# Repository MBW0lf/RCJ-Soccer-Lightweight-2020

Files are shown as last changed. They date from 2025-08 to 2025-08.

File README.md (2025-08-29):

# ⚽ Nemesis – Junior Soccer Lightweight Robot

This project is a soccer-playing robot developed by the Nemesis team from Allame Helli 5 High School for the IranOpen RoboCup competition. The robot is designed to detect, chase, and control an infrared-emitting ball, navigate the field, and play both offensive and defensive roles.

## 🛠 How it works
- Ball detection using IR sensors (IRM8601S) placed around the robot.  
- Positioning & orientation with a GY-25 gyroscope module.
- Line detection with multiple LDR sensors to avoid going out of bounds.  
- Offensive & defensive algorithms to coordinate striker and goalkeeper roles.  

## 🔧 Hardware Components
- **STM32F103C8T6**: 32-bit ARM microcontroller for main control 
- **IRM8601S IR Sensors**: ball detection in 16 directions 
- **GY-25 Gyroscope**: orientation tracking 
- **SHARP GP2D120 Sensors**: distance measurement for walls and positioning 
- **L6203 Motor Drivers**: high-current motor control  
- **DC Gear Motors (555 RPM)**: omnidirectional movement with mecanum/omni wheels
- **LDR Sensors**: line detection for field boundaries 
- **Custom PCBs**: lightweight structure and reduced wiring

## 📡 Communication
- Sensor data is read via **ADC** and **multiplexers** (4067 ICs).
- Motor control is handled by **PWM signals** from STM32.
- Algorithms adjust speed and direction based on ball position, field boundaries, and opponent location. 

## 🤖 Roles
- Striker: Actively chases the ball and aims for the opponent’s goal.
- Goalkeeper: Maintains position near own goal, intercepts incoming shots.

## 🚀 Innovations
- Increased number of **LDR sensors** for higher boundary detection accuracy.
- Dual multiplexer system to handle large numbers of sensors with limited pins.
- Modular design allowing quick replacement of gyroscope or compass modules.
- LCD display for real-time debugging and sensor data visualization.

## Summary
The Nemesis robot demonstrates how **sensor fusion, mechanical design, and embedded programming** can be combined to create a competitive RoboCup soccer robot. Its design focuses on **speed, precision, and adaptability** in dynamic match conditions.  

---

✨ *Thanks for checking out this project!*

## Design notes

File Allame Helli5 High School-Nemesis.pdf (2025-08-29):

پانزدهمین دوره مسابقات بینالمللی ربوکاپ آزاد ايران دانشگاه آزاد اسالمی قزوين و کمیته ملی ربوکاپ ايران
تهران | فروردين 1399

## گزارش فنی تیم Nemesis

### (Junior Soccer Light Weight)

،محمد مهدی قاسمی | 1 | طاها علیخانی

2

3 ،امیرحسین کشاورز
،سیدامیرعلی نواده

4
تهران،میدان فردوسی،خیابان ایرانشهر،دبیرستان پسرانه تیزهوشان عالمه حلی5
NemesisteamH5@gmail.com

## چكیده

در این مقالهه بهه شهرر مراحها یراحهی و سهاخه رباتههال فوتتالیسهه تهی Nemesis پرداختهه شهدا اسههارباا ههال ایهن تی متشکا از سهه بشها ایهلی مکانیل،الکترونیهل،التوریت و برنامهه نویسهی اسهها مها بها اسهتاادا از هههار موتهور DC کهه سهرعتی حهدود پانصهد و پنجهاا و پهن دور در دقیقهه و ههره ههال خورشهیدل trans)کهه امکهان حرکهه در تههامی ههاا را با هدف دنتها کهردن تهو بهرال ربهاا فهراه مهی کنهد اسهتاادا کهردا ای اسهشه افهزار یراحهی شهدا توانهایی تشهشی پههالم مههادون قرمههز ارسههالی از تههو را بههه کهههل سنسههور هههال 8601IRM دارد و پههم از تشههشی تههو ، دسههتور ههها و فرمان کنترلی الزم توسه میکروکنترلهر 32STM بهه درایهور موتهور 6203L ارسها مهی شهودادر ههر کهدام از ایهن بشها هها زیر مجهوعه هایی و ود دارد که در ادامه به یور کاما به آن ها اشارا می کنی ا

IRM8601 ، L6203 ، STM32F103C8T6 ، DC | موتور | : | کلیدی | واژههای

## .1 مقدمه

ربات ها ، بازیگران عصر تكنولوژی: انجام بعضهی ازامهور بهرال مها انسهان هها شهاید بسهیار خسهته کننهدا و عهدا آور باشهدا امها بعضهی از امهور حتهها بایهد انجهام شهوندا پهم مها دو راا بیشهتر نهداری او اینکهه کهار ههال خهود را بها هههان سهشتی انجهام دههی یها اینکهه بها اسهتاادا از ذههن خهالخ خهود امهور را بهه بهازیتران عصهر تکنولهویل بسهتاری ارباا هها هههان بهازیتران عصهر تکنولهویل هستند بازیترانی که روز به روز بیشهتر خهود را در معهری دیهد عههوم میتدارنهدااز ارسها بسهته ههال پسهتی رفتهه تها حتی ورزش مههی و پریرفهدار فوتتها کهه مهورد تو هه تهی مها قهرار رفهه و بهه فکهر تشهکیا تهی ربهاا فوتتالیسهه ستل وزن و شرکه در مسابقاا ایران اپن پرداختی ا

-1 برنامه نویسی
-2 الکترونیل و مکانیل
-3 الکترونیل و مکانیل
-4 برنامه نویسی

تهران | فروردين 1399

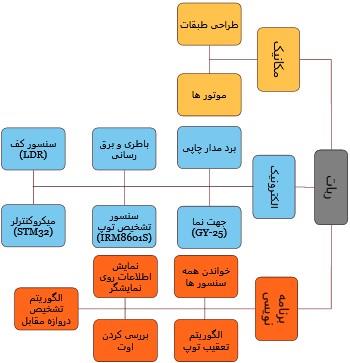
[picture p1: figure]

شكل :1یار تا ید رباا در یل نتاا

## .2 سیستم حرکتی:

.2.1 مكانیک سیستم حرکتی:

.2.1.1 بدنه
- بدنه رباا به یور کلی شاما سه یتقه میتاشد که هر یتقه از نم مدار هاپی و در برنامه DESIGNER ALTIUM یراحی شدا اسه:
- شاسی یا کای رباا از ههار موتور و هره ها و مدار LDR تشکیا شدا اسها
- بشا دوم محا قرار یرل سنسور هال مادون قرمز 8601IRM (اسهاکه کار تششی تو را انجام می دهندا
- بشا سوم محا قرار یرل باقی قطعاا الکترونیکی اسها

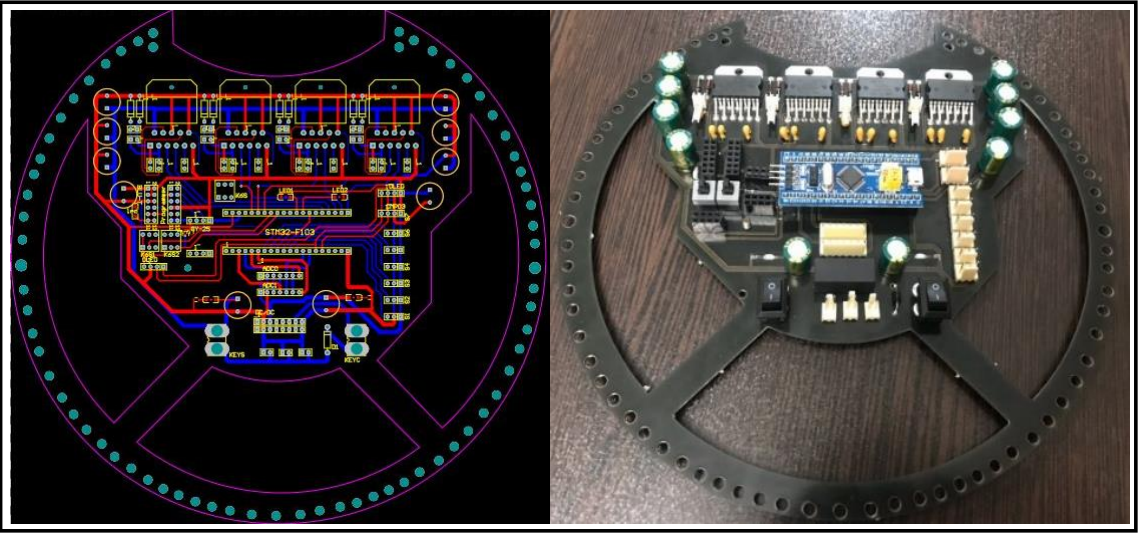
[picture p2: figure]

شكل:2 نهال رول رباا

تهران | فروردين 1399

.2.1.2
موتور ها و چرخ ها:
سیستم دو موتور و دوچرخ: با تو ه به اینکهه ههر ههه تعهداد موتهور هها کهتهر باشهد وزن نههایی ربهاا نیهز کهتهر میشهود،پم بهتهر اسهه کهه از دو موتهور قهویتر بها امکانهاا بیشهتر اسهتاادا کهرد، بهه ایهن منتهور مهی بایسههه دو موتهور بها زاویهه180 در ه نسته به هه و و 90 در هه نسهته بهه لهول ربهاا قهرار یرنهدا در نتیجهه یتها ایهن سیسهت ،رباا مهی توانهد در دو ههه ایهلی حرکهه کنهدااما در ایهن یهورا سهرعه عکهم العهها و قهدرا مهانور رباا کهتر می شودا در نتیجهه زمهان زیهادل نسهته بهه دیتهر سیسهت هها بهرال بهه دسهه آوردن تو ،باز شهه بهه دروازا و ااا تلف می شودا به این دالیا ما از این سیست استاادا نکردا ای ا سیستم سه موتور و سه چررخ: بهرال داشهتن سهرعه مناسهت ههه مهانور و عکهم العهها میتهوان از سیسهت سهه موتههور و سهه ههره اسهتاادا نههود. بهرال اسهتاادا از ایهن سیسهت مهی بایسهه موتورهها بازاویهه120در هه نسته به هه قهرار یرنهدا ایهن سیسهت بهه 6 ههه ایهلی و 6 ههه فرعهی تهوان حرکتهی داردا ایهن سیسهت بهه یور نستی از سرعه،مانور باال و ههچنین وزن ک برخوردار اسه اما سرعه مطلو مورد نیاز ما را نداردا

شكل :3 حاله هال مشتلف قرار یرل هره ها سیستم چهار موتور و چهرار چررخ: در ایهن سیسهت بهه دلیها اسهتاادا از هههار موتههور،ربههاا توانههایی مههانور و عکم العهها سهریر را داردا در ایهن سیسهت 4 موتهور بها زاویهه 45 در هه نسهته بهه هه اسهتاادا شهدا اسهه و ربهاا مهی توانهد در 8 ههه ایهلی و 8 ههه فرعهی حرکهه کنهدا در ایهن سیسهت تهراز بهودن ههر هههار ههره اههیهه بهاالیی دارد و ههچنهین بها تو هه بهه تعهداد موتهور هها و محهدودیه وزنهی مشهش شهدا از سهول کهیتهه مسههابقه بایههد از موتههور هههال سههتل تههر و اههعیف تههر اسههتاادا کنههی ا مهها از موتههور هههال تههایوانی GEAR DC MOTOR بها ولتهای کهارل-15 9 ولهه و 555 دور در دقیقهه اسهتاادا کهردا ایه کهه بیشهتر شهاخ ههال مهورد نیاز ما را دارا هستندا

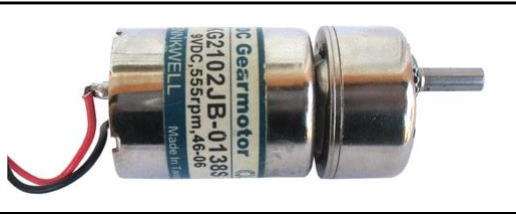
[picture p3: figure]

شكل:4 مششصاا موتور

KG2102JB-0138S | مد شهارا
یو : 45 میلی متر | ابعاد شعاع: 25 میلی متر
| بازا ولتای کارل 9-15 وله
| تعداد دور در دقیقه rpm )555 دور در دقیقه
| وزن 75 رم

تهران | فروردين 1399

چرخهای خورشیدی:
هره ههال تهرنم خورشهیدل( ههره ههایی هسهتند کهه از یهل ههره سهادا و تعهدادل ههره هرز هرد متصها بهه هره ایلی تشکیا شدا اندا ساختار ایهن ههره هها یهورل یراحهی شهدا اسهه کهه قابلیهه حرکهه در دو ههه را داراسه و این قابلیه، امکان حرکهه ربهاا در ههاا مشتلهف را آسهان تهر و سهریر تهر مهی کنهدا سهتل بهودن نیهز از ویژ ی هال مثته این هره هاسها

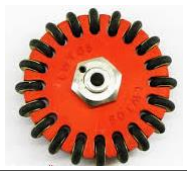
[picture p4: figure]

شكل :5 هره خورشیدل
.2.2 مدارات:
:stm32f103 | میكروکنترلر
ایههن میکروکنترلههر هههال 32 بیتههی از خههانوادا میکروکنترلههر هههال ARM هسههتند کههه بههه هنههدین روش قابهها برنامههه ریههزل و اسهتاادا هسهتندا یکهی از ایهن روش هها اسهتاادا از نهرم افهزار uvision MDK Keil اسهه کهه بسهیار قدرتهنهد بهودا و قابلیهه هال بسیارل داردا روش دیتر اسهتاادا از نهرم افهزار IDE Arduino اسهه کهه بسهیار سهادا و قابها فهه میتاشهدا مها بها اسهتاادا از نهرم افهزار IDE Arduino کهد خهود را بهر رول میکروکنترلهر پیهادا میکهردی ا بهوردل کهه مها از آن در ربهاا اسهتاادا کهردی بهورد 6T8C103F32STM اسهه بها فرکهانم 72 MHZ بها حافتهه فلها 64KB کهه شهاما یهل میکروکنترلهر 32STM ، مهدار پرو رمر،مدار تغدیهه ، در هاا miniUSB وااا میتاشهدامیکرو کنترلهر ههال STM را میتهوان از هنهدین یریها پرو هرم کهردا مها بها اسهتاادا از یهل متهد USB بهه سهریا RL23FT )و ههچنهین بها اسهتاادا از در هاا miniUSB در نهرم افهزار IDE Arduino آن را پرو رم میکنی ا
میکروکنترلرهههال ARM نسههته بههه میکروکنترلرهههال دیتههر ماننههد AVR مزیههههال بسههیارل دارنههد از هلههه فرکههانم بسههیار بهاالتر، 32بیتهی بهودن، یهو عههر بسهیار بهاال، قابها ایهینهان بهودن و اااا اههچنهین نسهته بهه خهانوادال AVR کامتایلرههال پیشرفتهال برال برنامهنویسی این خانوادا از میکروکنترلرها در دسترس اسها

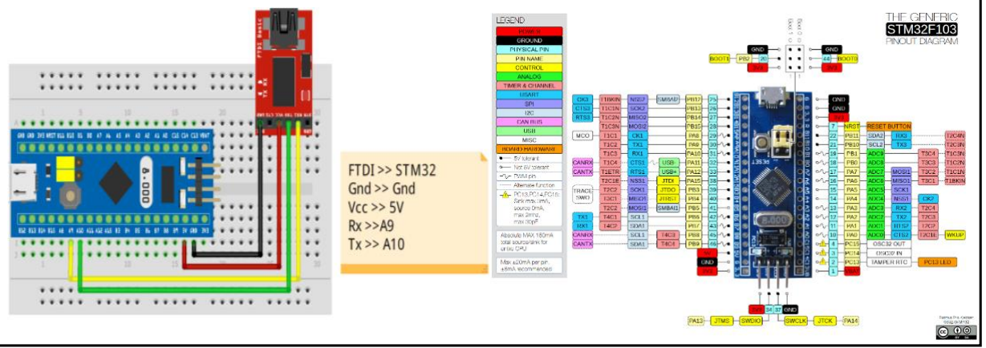
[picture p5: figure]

شكل:6 پایه هال 6T8C103F32STM و نحوا اتصا آن به RL23FT

تهران | فروردين 1399

درایور موتور:

6203L و 298L قطعاتی هسهتند کهه بهرال درایهو کهردن موتهور ههال DC از آن هها اسهتاادا مهی شهودادرایهور 298L بها قابلیه درایو کهردن هه زمهان 2 موتهور، درایهور بسهیار مناسهتی از لحهای وزنهی اسهه امها بهه دلیها ریهان دههی پهایین امکان از کار افتادن این درایور و هود دارد ا در ایهن حها درایهور 6203L بها قابلیهه درایهو یهل موتهور و تهوان آمتهر کشهی تا 4 آمتر مورد استاادا تی ما قرار رفها

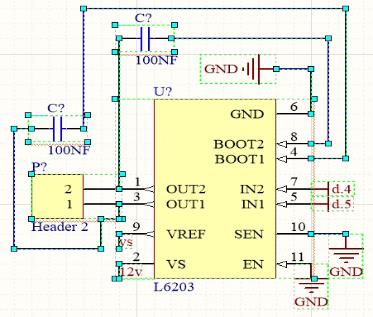
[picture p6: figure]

شكل:7 بایاس درایور 6203L

.2.3 الگوریتم برنامه نویسی شده و فرمان به موتور ها: در کد برال حرکه رباا تابر خایی در نتر رفته شدا که در این تابر عدد سرعه و هه هره موتور وارد میکنی و رباا با دریافه این ایالعاا با تو ه به قطعاا استاادا شدا در ساخه آن با ک زیاد کردن ولتای سرعه موتورها و با ابه ایی بار مثته و منای وارد به موتور هه هره را عوی میکندا ماکسیه عدد سرعه 65535 و مینیه آن 0 اسه اما به دلیا فرکانم کارل حداقا مقدار سهرعه ههه حرکهه 10000 اسهه کهه ایهن عهدد بهه یهورا تجربهی بهه دسهه آمهههههههدا اسهههههههه و هه هره با مثته و یا منای بودن عدد تعیین میشودا به یورل که ا ر عدد مثته باشد موتور پادساعه رد و ا ر منای باشد ساعه رد می هرخدا

## .3 تشخیص توپ:

.3.1 سنسورها:
بهرال تشهشی تهو از 16 سنسهور تشهشی دهنهدا پهالم مهادون قرمهز S8601IRM اسهتاادا کهردا ایه ا نحهوا هیهدمان این سنسور ها در 8 ههه حرکهه ایهلی و 8 ههه فرعهی ربهاا قهرار داردامها از ایهن سنسهور بهرال تشهشی فایهله تهو تها رباا استاادا کردا ای تا رباا دروازا بان داشته باشی ا بایاس این سنسور با دو مقاومه k33 و k22 و یل خازن 1 میکرو فاراد به یورا زیر اسه:

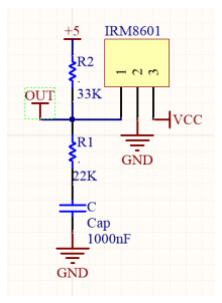
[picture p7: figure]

شكل:8 سنسور S8601IRM و بایاس آن

تهران | فروردين 1399

.3.2 برنامه نویسی:
برال خواندن سنسور ها از پایه ل 1A در میکروکنترلر 32STM استاادا شدا که این پایه دارال ADC میباشد. (DigitalConverter To Analog(ADC متد آنالوگ به دیجیتا اسه و کار آن این اسه که سیتنا هال آنالوگ را از سنسور ها دریافه کردا و به دیجیتا تتدیا میکندا

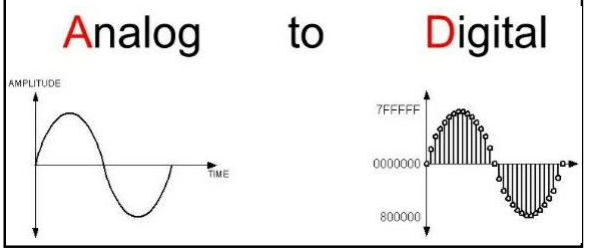
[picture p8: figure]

شكل :9 تتدیا پالم آنالوگ به دیجیتا

سنسور ها هنتامی که اشعه ساطر شدا از تو را دریافه میکند یل موج آنالوگ و هنتامی که اشعه ال دریافه نهیکند یل موج ماننههههههد نهههههههودار( میدهد که ما این تغییراا را به یورا عدد دریافه میکنی و با تو ه بههههههه اعداد دریافه شدا آ اا میشوی که کدام سنسور تو را مشاهدا میکند ستم با دادن هه هرخا به موتور رباا را در هه آن سنسور هدایه می کنی ا

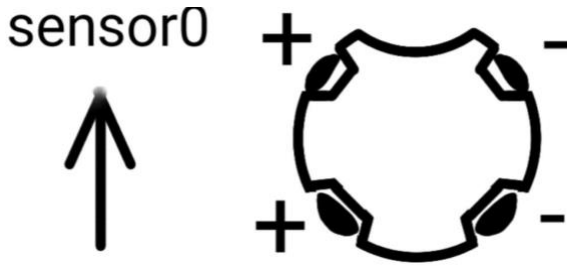
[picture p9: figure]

شكل :10 با دادن مقادیر مناست حرکه سنسور0را به سهه لو( ا را میکندا

## .4 تشخیص دروازه ها:

.4.1 سنسور ها:
برال تششی اهداف از مهایو ییروسهکو -25GY اسهتاادا کهردی ا دلیها اسهتاادا از ایهن مهایو پهایین تهر بهودن میهزان نهویز آن نسهته بهه مهایو قطهت نههال 03CMP اسهه. ایهن مهایو ییروسهکو دارال تراشهه -6050MPU و MCU اسهه و ولتهای ورودل ایهن مهایو 3 تها 5 ولهه اسهه و بها دو پروتکها C2I و UART قابها اسهتاادا اسهه کهه مها از یریها پروتکها UART بههین مههایو ییروسههکو و میکروکنترلههر ارتتههاط برقههرار مههی کنههی بههرال برقههرارل ایههن ارتتههاط دو پایههه Rx و Tx را بههه میکروکنترلر ویا می کنی .

تهران | فروردين 1399

مها نیهز بهرال کهامتم یها قطهت نههال دیجیتها 03CMPS نیهز هایی داشهتی کهه ا هر احیانها در هنتهام بهازل مشهکلی برال مهایو -25GY پهیا آمهد بتهوانی سهریر آن را هایتزین کهردا و از آن اسهتاادا کنهی ایهن مهایو نیهز از یریها ارتتهاط C2I با میکروکنترلر ارتتاط برقرار مهی کنهدا ههچنهین ایهن مهایو بها تو هه بهه مغنهاییم زمهین بهازت تغییهراا بهین 0 تها 255 می باشد که بر خالف -25GY با پایه هال SDA و SCL میکروکنترلر ارتتاط برقرار می کندا

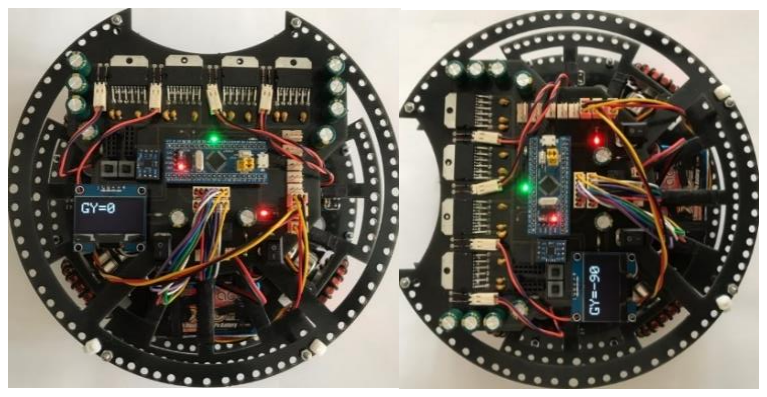
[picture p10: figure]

شكل :12 مقادیر مشتلف -25GY برال هاا متااوا .4.2 الگوریتم ها:
با فرستادن کد هال اختصایی مایو مو ود در دیتا شیه آن( با هر هرخا رباا از سنسور اعدادل را دریافه میکنی که این اعداد را به کهل کد برنامه نویسی شدا از +180 تا -180 تنتی میکنی ا 0 این بازا هنتامی اسه که دهانه رباا ههراستا با هتی قرار یرد که هنتام روشن شدن در آن هه بودا باشدا ما برال اینکه رباا دروازا حریف را از خودل تششی دهد، آن را رو به دروازا حریف قرار میدهی ا ههچنین برال اینکه رباا در حین حرکه هه خود را رو به دروازا حاظ کند و تو را به به سهه آن هدایه کند در بازاهال مشتلف اعدادل که از مایو میتیری ، اعدادل را به سرعه موتور ها ااافه میکنی که این اعداد حایا آزمایا هال بسیار هستندا

## .5 تشخیص خط اوت:

.5.1 سنسورها:
ما با استاادا از 4 عدد سنسور SHARP در هه هال هپ،عقت و راسه و لول رباا( و 32 عدد LDR فایله تا اوا و خ اوا را تششی می دهی ا ما می توانستی از سنسور هال ULTRASONIC ه استاادا کنی اما برال استاادا از هرکدام از این سنسور ها در کد باید از دو تأخیر50 میلی ثانیه استاادا کرد که در نتیجه به ازال ههار سنسور ، باید 400 میلی ثانیه تأخیر داد که در کار ما تاثیر منای زیادل داردا از یرفی نیز ران بودن این سنسور و نداشتن بود ه کافی عاما دیتر استاادا نکردن از این سنسور اسها سنسور هالSHARP به پایه هال ADC میکروکنترلر 32STM متصا اندا به دلیا کهتود پایه برال اتصا 32 LDR مو ود در بشا کای و16سنسور 8601IRM در یتقه دوم رباا، ما با استاادا از دو مولتی پلکسر 4067 در هر دو یتقه ، مقادیر مشتلف سنسور هال دو یتقه را با پایه Z مولتی پلکسر دریافه می کنی ا این مولتی پلکسر 24 پایه دارال 4 پایه آدرس برال باینرل کردن اعداد16، پایه برال دریافه ایالعاا از سنسور ها و 4 پایه VDD، VSS، ENABLE و یل پایه Z اسها

شكل:12 پایه هال آلسی 4067

تهران | فروردين 1399

.5.2 مدارات و چیدمان:
مدار LDR ما شاما دو مقاومه نورل ، یل LED و دو مقاومه میتاشدا 4عدد LDR در نیهه راسه4،عدد در نیهه هپ ، 4 عدد در نیهه باال و 4 عدد در نیهه پایینی تعتیه شدا اسها LED بر زمین نور میتاباند و میدانی که بازتا نور هر رنگ با دیترل متااوا اسها در نتیجه ما میتوانی با استاادا از این مدار تااوا میان رنگ ستز زمین( و رنگ ساید خ اوا( را تششی دادا و مانر عتور رباا از خ اوا شوی ا

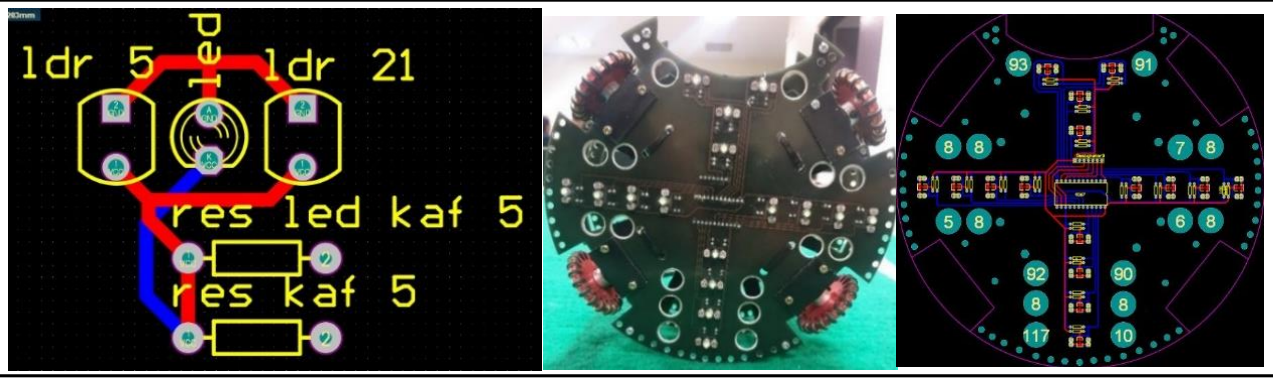
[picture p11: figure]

شكل:13 بایاس و نحوا قرار یرل LDR

.5.3 الگوریتم ها:
ربههاا ههههوارا مقههدار LDR را میتیههردا مهها ههه مقههدار LDR رول خهه سههاید را بههه یههورا دسههتی در کههد وارد میکنههی ا بهها استاادا از دادا ها، رباا را برنامهه ریهزل میکنهی کهه هنتهامی کهه دو مقهدار برابهر شهدند، ربهاا در هههان ها بایسهتد و یها بهه عتارتی مقدار ههه موتور ها یار شودا ا ر دو مقدار برابر نتودند، رباا به تعقیت تو بتردازدا

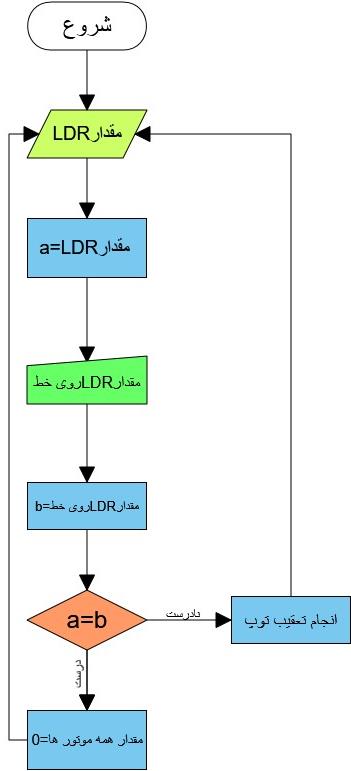
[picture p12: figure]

شكل:14 التوریت تششیض تو با استاادا از LDR

تهران | فروردين 1399

## .6 مهاجم:

.6.1 الگوریتم ها:
رباا مها به ونهال برنامه ریزل شدا اسه که در یورا نتود تو به عقت بر نتردد و با استاادا از شار هال هپ و راسه در بازاال در عری زمین قرار بتیردا ما با استاادا از روش هال خایی سعی کردی که رباا ههوارا تو را به دروازا حریف هدایه کندا ایالعاا تکهیلی در نوآورل توایح دادا شدا اسه.

## .7 دروازهبان:

.7.1 سنسورها:
سنسور SHARP)120D2GP (دارال دو بشا فرستندا و یرندا می باشدا فرستندا پالم هال مادون قرمز را ایجاد میکند و به خارج سنسور ارسا می کند و بشا یرندا دارال لنز مشصویی اسه که زاویه دریافه پالم را تششی دادا و با تو ه به آن مقدارل آنالوگ را به میکروکنترلر 32STM زارش می دهدا این سنسور با ولتای کارل 5-4 وله با خرو ی آنالوگ فایله 4 تا 30 سانتی مترل را زارش می دهدا شاید سوا باشد که هرا محدودا کارکرد این سنسور از 4 سانتی متر به بعد اسها با تو ه به نهودار می توان پی برد که این سنسور تا ههار سانتی مترل نهی تواند خرو ی درسه بدهد و دادا پرا می دهدا سنسور هالSHARP به پایه هال ADC میکروکنترلر 32STM متصا انداهرهه زاویه بیشتر باشد، رباا به دیوارا نزدیکتراسها نسته تغییراا زاویه به تغییراا فایله به یورا یل ولتای متغیر در خرو ی دادا میشودا

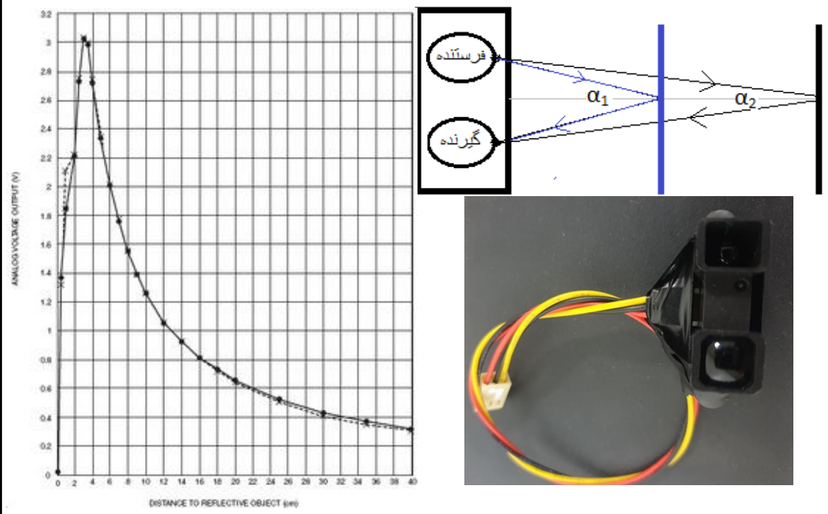
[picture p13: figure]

شكل:15 نحوا عهلکرد سنسور شار و نهودار مقادیر مشتلف به ازال فوایا متااوا

تهران | فروردين 1399

.7.2 الگوریتم ها:
یکی از رباا ها به ونه ال برنامه ریزل شدا اسه که از نیههل زمین لوتر نرود تا در هنتام حهلههال غافلتیرانه حریف مانر از اخوردن شودا این التوریت با استاادا از شار ها پیادا سازل میشود که در بشا نوآورل ایالعاا بیشترل در این بارا ارایه شدا اسها

## .8 نوآوری ها:

.8.1 طراحی مكانیكی
ما با اسهتاادا از بهرد ههال ههاپی بها که کهردن مقهدار سهی ههال اسهتاادا شهدا در ربهاا باعهک کهاها وزن بسهزایی شدی ا
.8.2 طراحی مدارات و سنسور ها مها در کهف ربهاا از حهد معههو تعهداد بیشهترل LDR بهه کهار بهردا ایه کهه سهتت میشهود دقهه ربهاا بیشهتر شهدا و احتها اوا رفهتن آن کهتهر شهودا ههچنهین بهرال ههر یتقهه از یهل آیسهی 4067 اسهتاادا کهردا ایه کهه سهتت میشهود تعههداد کهتههرل سههی و اتصههاالا از یتقههاا پههایینی بههه یتقههه فوقههانی بیایههدا بههرال تعقیههت تههو از سنسههور هههال S8601IRM اسهتاادا کهردی کهه افهزون بهر میهدان دیهد بیشهتر، بهه ازال ههر مقهدار فایهله تهو از ربهاا مقهدار معینهی میدههد و مها میتهوانی بهه ازال ههر مقهدار آن برنامهه و التهوریتهی مشهش کنهی ا اسهتاادا از بهرد 6T8C103F32STM ستت میشود تا سرعه و دقه پهردازش افهزایا یابهدا هههان یهور کهه مهی دانیهد قطهت نهاههال دیجیتها براسهاس میهدان مغناییسی زمین عها مهی کننهد ولهی مشهکا اینجاسهه کهه ههر میهدان مغناییسهی دیتهرل بهر خرو هی آنهها تهاثیر مهی ههدارد کههه ایههن بههه معنههال خطههال زیههاد آنههها اسههها پههم مهها در ربههاا خههود از یههل مههایو غیههر وابسههته بههه میههدان مغناییسی -25GY )استاادا کردی اما بهرال اسهتاادا از یهل قطهت نههال دیجیتها نیهز مکهانی اختصهاا دادیه ا بهه سهه روش می تهوان میکروکنترلهر را پرو هرام کهرد و ایهن یکهی از مزایهال مهه ایهن میکروکنترلهر اسهها مها بجهال اسهتاادا از LCD هههال کههاراکترل رایهه در بههین بقیههه تههی ههها کههه دارال محههدودیه هههال زیههادل هسههه، از DISPLAY OLED استاادا کردی که میتوان دادا ههال مهورد نیهاز را در هههه هال آن و بها انهدازا مهورد نیهاز نشهان داد و ههچنهین پایهههال کهترل ه نسته به LCD هال کاراکترل اشغا میکندا

.8.3 برنامه نویسی و الگوریتم ها رباا ها به ونه ال برنامه ریزل شهدا انهد کهه هنتهامی کهه تهو توسه سنسهورها تشهشی دادا نشهد تو در زمهین نیسهه( و با استاادا از سنسور ههال فایهله سهن (SHARP(، فایهلهل خهود را از دیهوارا ههال کنهارل و پشهه زمهین انهدازا میتیهرد و به یورا عدد به میکروکنترولهر میارسهتدا مها بها اسهتاادا از ایهن اعهداد، بهازا ههایی را بهرال ربهاا تعریهف میکنهی کهه وقتهی رباا در آن بازا ها نتود بها ابهه هایی در زمهین، خهود را وارد منطقهه مهورد نتهر میکنهد .بها اسهتاادا از ایهن قابلیهه یکهی از رباا ها نسته به دیتهرل مقهدارل عقهت تهر هایتیرل میکنهد بهه یهورل کهه میتهوان اهه نقها دروازا بهان را ایاها میکنهد . این قابلیه برال ان اسهه کهه ا هر یکهی از ربهاا ههال حریهف از یکهی از ربااههال مها پیشهی رفهه ربهاا دیتهر در عقهت آن باشد و از ها خهوردن لهو یهرل کنهد. در ارتتهاط بها ربهاا مهها بایهد بهه ایهن نکتهه اشهارا کهرد کهه وقتهی داور تهو را از زمین خهارج میکنهد ربهاا بها تو هه بهه تواهیحاا دادا شهدا در بشها 6.1 بهه عقهت بهر نهیتهردد و در میانهه زمین نسهته بهه عری( ایتیرل میکند و این قابلیه بهه ربهاا مهها ایهن ا هازا را میدههد تها بها قهرار دادن تهو توسه داور در نقهاط خنثهی زمین نسته به رباا حریف بسهیار سهریر تهر مالکیهه تهو را در دسهه بتیهرد عهالوا بهر آن ا هر ربهاا در فایهله مششصهی از دیوارا روبرویهی و دیهوارا ههپ و راسهه قهرار بتیهرد دهانهه خهود را هرخانهدا و رو در رو بها دروازا حریهف قهرار میدههد و تهو را از کنارا هال زمین بهه سههه دروازا حریهف ههدایه میکنهدا در نتیجهه در هنتهام حهلهه احتهها ههدایه تهو بهه اوا پشهه دروازا حریف ناهیز میشود و این باعک افزایا احتها ا زدن میشودا

تهران | فروردين 1399

## .9 روبات نهایی:

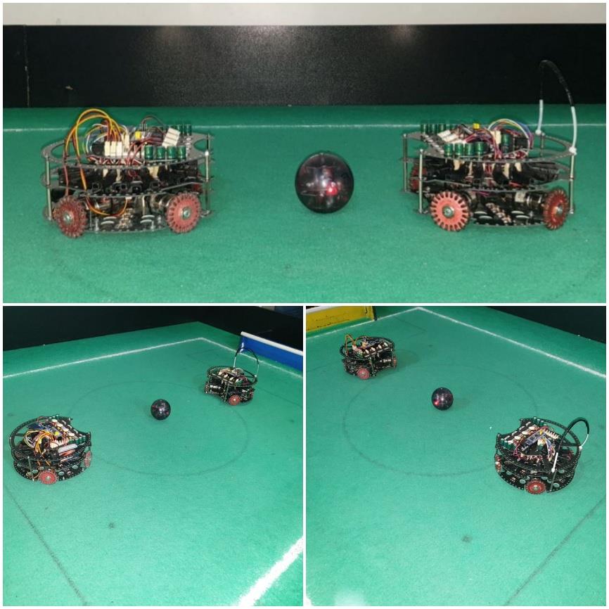
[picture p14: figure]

شكل:۱۶ نهایی از رباا

## .10 تشكر و قدردانی:

با تشهکر از مسهوولین دبیرسهتان عالمهه حلهی 5 دورا دوم( و ههچنهین بها تشهکر از مسهووالن بر هزارل مسهابقاا کهه ههکهارل الزم را با ما داشتند و ههه کسانی که مارا در این پرویا یارل کردااندا

## .11 مراجع:

-1و سایه رسهی شرکه میکروکنترلر هال ST و خالیه ال از میکرو کنترلر هال سرل 32STM /com.st.www://https (https://www.st.com/)

https://www.adafruit.com/ adafruit | سایه | و -2
https://www.arduino.cc/ Arduino | رسهی | سایه | و -3

https://www.roboeq.com/-4

https://www.alldatasheet.com/-5

https://www.eca.ir/-6
